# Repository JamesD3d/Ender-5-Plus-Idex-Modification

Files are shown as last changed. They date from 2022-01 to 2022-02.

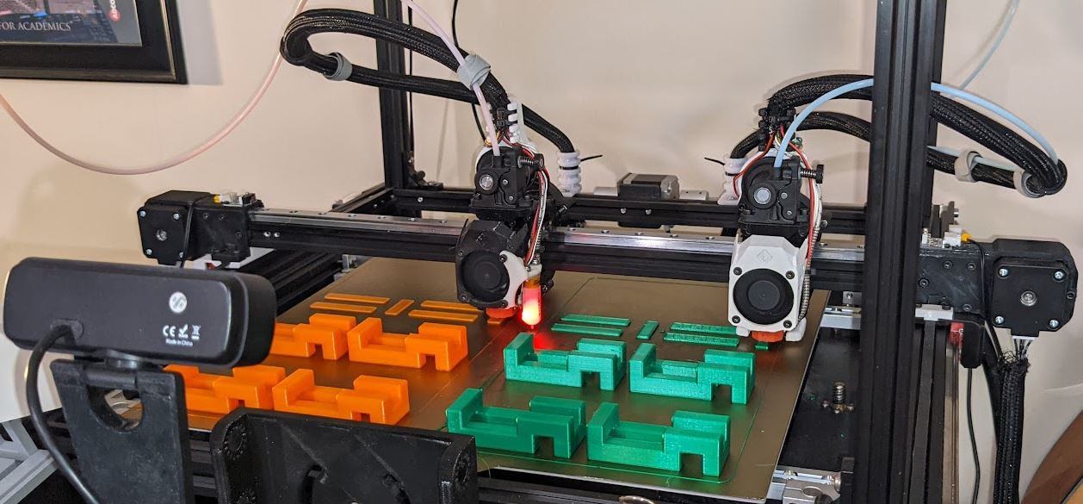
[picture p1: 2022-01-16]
Photos/Capture.JPG

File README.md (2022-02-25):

# Ender-5-Plus-Idex-Modification
This is a repo created for files and software related to the modification of an Enrer 5 plus into an Idex machene. 

Assembly instructions can be found here
<p><a class="inline_disabled" href="https://instructions.online/?id=2779-idex" target="_blank" rel="noopener noreferrer">Assembly Instructions</a></p>  
Firmware modification by S.Downer for Marlin Firmware
Klipper Mirror and Copy modes are not avaliable at this time
RipRap configuration is untested. 

Printer Modifications Require at least 6 independent Drivers
  X0 - X1 E0 - E1 - Y - Z
  X0, E0 = TO X1,E1 =T1
  
 The resulting bed size is as follows
    Stock = 377 x 370
    Dual Color / Full Controll Mode = 350 x 377
    Duplication Mode = 185 x 370
    Mirror Mode = 175 x 370
    
 Printing:
    All files shoud print w/out out supports with sacrafichial layers
    Extra perimiters are recomended. 
    Parts are designed and printed in PETG but ABS should work as well. 
    
 Retained Parts: 
    Many of the stock ender 5+ Parts are reused
    Many Nuts and Bolts
    Stock Y axis Belts
    Stock V slot wheel spacers
    
Eva 2. Tool head
    Please see the eva tool head system for instructions. 
    Most of the parts are customized
        Idex Back Plate
        Fand Duckt
        Universal Face plate
        Copperhead mount
        
The copperhead hotend is highly recomended as it is adjustable and really the only way to get a perfect z offset between both tools. This is a requirement for Duplication and Morror Modes to work.

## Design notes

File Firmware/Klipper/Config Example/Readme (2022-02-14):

The Klipper FIles do not curently support Mirror and Copy modes in Ideax configurations. This is a non functioning example of the config needed once complete.

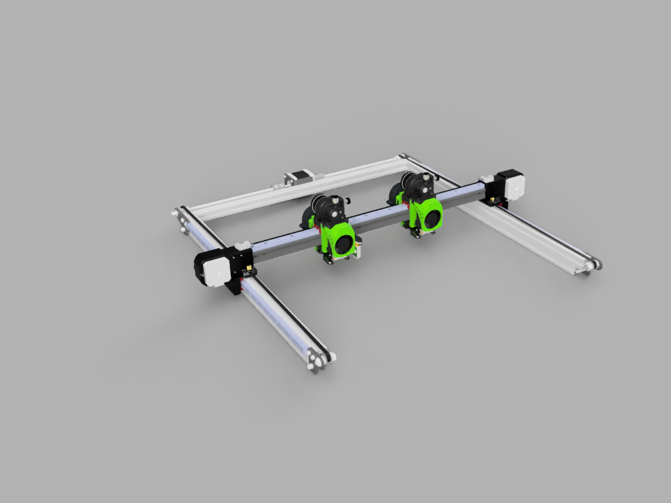
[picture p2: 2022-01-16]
Photos/Ender_5_Plus_Idex_Conversion_2022-Jan-16_10-52-59PM-000_CustomizedView14178243556.png

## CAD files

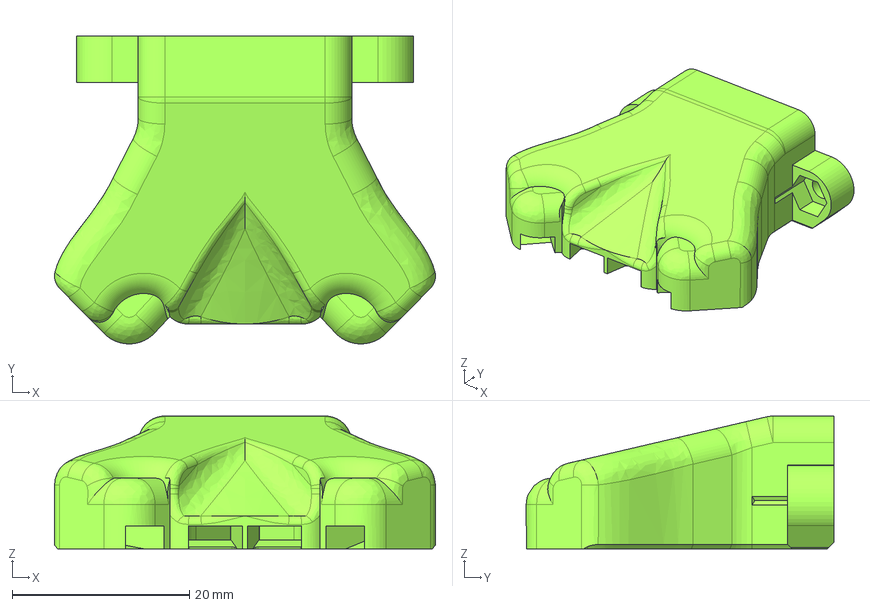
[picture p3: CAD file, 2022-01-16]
.step/S.Downer Fan and Copper/Compact Fan.step
43.0 x 34.7 x 15.0 mm

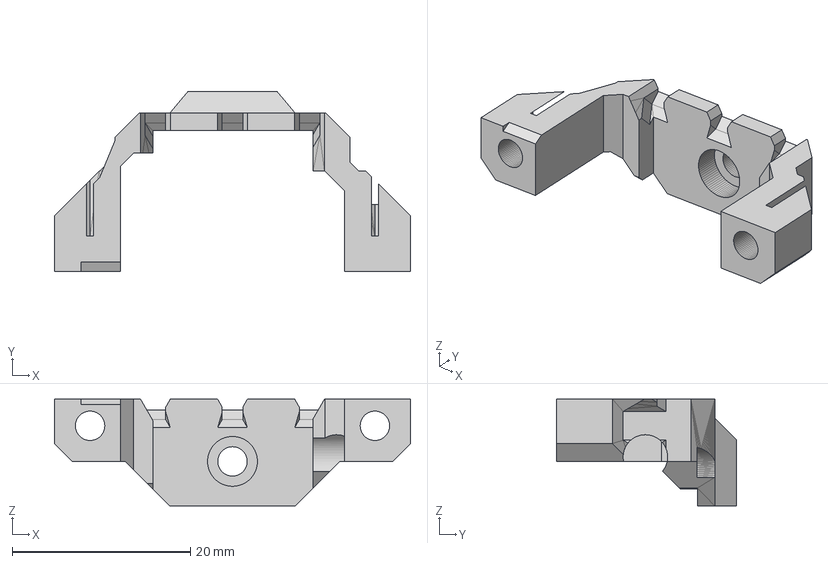
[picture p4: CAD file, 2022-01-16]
.step/S.Downer Fan and Copper/Copperhead Custom Support.step
40.0 x 20.3 x 12.0 mm

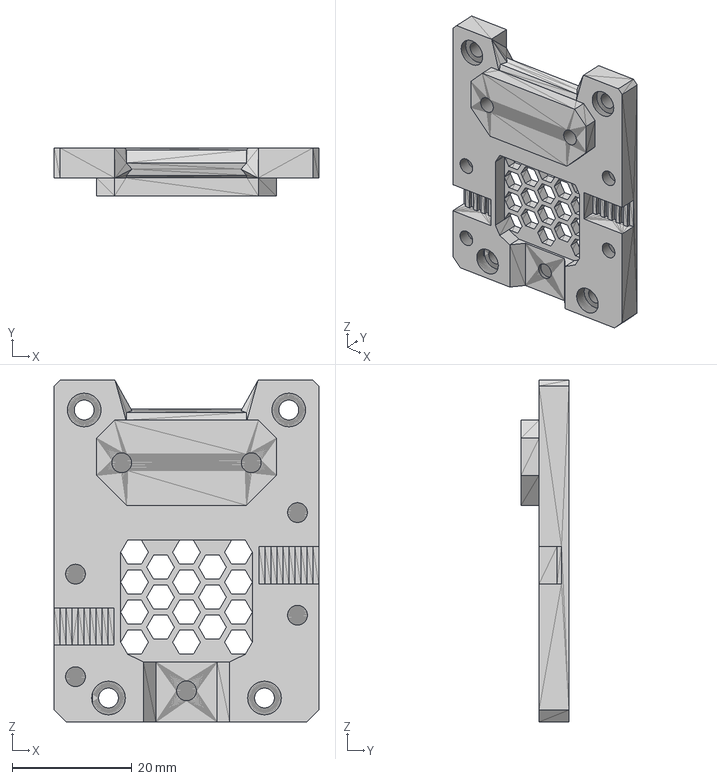
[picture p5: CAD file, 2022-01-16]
.step/S.Downer Fan and Copper/Copperhead X Carriage Front.step
44.1 x 8.00 x 57.0 mm

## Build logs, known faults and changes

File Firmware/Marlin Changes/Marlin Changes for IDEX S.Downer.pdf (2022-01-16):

Purpose of this Document
There is very limited documentation available for a Marlin based IDEX setup, and number of the key settings are quite difficult to work out without lots of trial and error.
The purpose of this document is to describe the main Marlin changes required for an IDEX set up, and to explain what these settings do where necessary.
The document assumes that the reader is familiar with editing Marlin source code, and is able to determine the correct values for the remainder of the configuration required for their particular 3d printer.

Basic hardware requirements for IDEX setup
Stepper Motors
The selected motherboard needs to support a minimum of 6 stepper motors. These are broken down as follows, but the total number will depend on the setup of your particular printer:
- X Axis. 2 identical stepper motors are required, each motor will be responsible for moving 1 of the 2 extruders.
- Y axis. 1 stepper motor
- Z axis. 1 stepper motor (minimum, but 3 independent steppers recommended as best in class solution (note this requires BL touch of equivalent))
- Extruders. 2 identical stepper motors are required, one for each of the two extruders.
For stepper motor selection, regular 42-34 stepper motors with 1.8 degree step angle are recommended. Whatever stepper motor is chosen, it is critical that the correct Vref / current values are configured to ensure correct printer operation.

End stop switches
If you are using a conventional endstop setup (rather than sensorless homing) you will require 1 additional end stop switch on the X Axis.
Note that with an IDEX setup, “Extruder 1” is the left hand extruder and homes to the left hand side of the print bed (the X Min direction), whilst “Extruder 2” is the right hand extruder and homes to the right hand side of the print bed (the X Max direction). This is why 2 end stop switches are required, and later in the Marlin configuration you will see that both XMin and XMax have to be setup correctly.

Choice of Hotend
It is critical with a dual extrusion setup that both nozzles can be adjusted to the same height, which ensures consistent filament extrusion. As a result, it is vital that at least one of the hotends selected has an adjustable height nozzle to match that of the other extruder.
The recommended setup is to use 2 x Copperhead hotends, and a custom mount has been designed to work with the popular EVA2 modular assembly (https://main.eva-3d.page/)

EVA2 is a great choice for an IDEX setup due to its range of supported hardware, and very compact design – ensuring that there is minimal loss of printing real estate on the bed in the X direction due to the IDEX assemblies getting in the way of each other.
Bed Probe
A bed probe such as a BLTouch is optional to this setup. If a bed probe is in use, Marlin expects the probe to be attached to Extruder 1 (the left hand IDEX assembly). This is not configurable without major code changes.

List of Marlin Changes to get IDEX working
configuration.h
Configuration Key | Configuration Value | Notes
#define EXTRUDERS | 2 | Change the default value from 1 to 2. This tells Marlin that you have a dual extrusion setup.

#define HOTEND_OFFSET_X | 0 | Leave this at the default value of zero. The settings later will deal with the relative positions of the two extruders.

#define USE_XMIN_PLUG | Enable by removing the “//” | As mentioned earlier, the two extruders home at opposite ends of the X axis. The XMin endstop is used for extruder 1.

#define TEMP_SENSOR_0 #define TEMP_SENSOR_1 | Enable by removing the “//” for “TEMP_SENSOR_1”. | Each hotend will have its own thermistor, and the second extruder needs enabling to support this. Ender the appropriate value for your thermistors

#define X_DRIVER_TYPE #define X2_DRIVER_TYPE | Enable “#define X2_DRIVER_TYPE” by removing the “//”. | Configure the correct stepper drivers for each X axis motor. Note that there may be other dependent values required for X2 depending on the stepper drivers, e.g. trinamic driver current in advanced configuration.

#define E0_DRIVER_TYPE #define E1_DRIVER_TYPE | Enable “#define E1_DRIVER_TYPE” by removing the “//”. | Configure the correct stepper drivers for each extruder motor. Note that there may be other dependent values required for E1 depending on the stepper drivers, e.g. trinamic driver current in advanced configuration.

INVERT_E0_DIR INVERT_E1_DIR | Set INVERT_E1_DIR to same value as INVERT_E0_DIR | This is a software setting that determines which way the

| | stepper motors move (can be adjusted by changing cable wiring layout too).
#define X_BED_SIZE #define Y_BED_SIZE | Example for Ender 5 Plus: 377 350 | The normal printable area may be different from the physical bed size. IDEX complicates this further as each extruder may not be able to reach part of the bed at each extreme of the X Axis. It is recommended you configure the X_BED_SIZE value to the physical dimensions of the bed. This value is used to determine the relative extruder position, and using the full size also means you lose the lowest possible amount of printing space.

#define X_MIN_POS | Example for Ender 5 Plus: -36 | When the left hand extruder homes, it will be parked off the left hand side of the bed. The default Marlin behaviour is to treat this as X=0. This needs to be adjusted so that X=0 is the left hand edge of the printer bed. The exact value used here will depend on your printer setup, but for an IDEX setup on a Ender 5+, this is a guide.

#define X_MAX_POS | Example for Ender 5 Plus: 412 | Similarly to above, when the right hand extruder is homed, it will move to the X axis maximum end stop. The default Marlin behaviour would be to assume this is equal to the maximum configured X axis bed size (e.g. 377). As at the maximum end stop position, extruder 2 is parked off the right hand edge of the bed, this is a value >377.

412 is the required
approximate value for a IDEX setup on a Ender 5+.

Configuration_adv.h
define X_CURRENT
define X2_CURRENT
define E0_CURRENT
define E1_CURRENT

Values suitable for your
stepper motors.

If you are using Trinamic
stepper drivers, you need to configure the correct current values for your motors.
Choosing too low a value will cause your motors to skip
steps, and too high will
cause overheating and
shorten their life.

A good rule of thumb:

Take the manufacturers
current specification for the motor, e.g. 1.5amps.

Divide this by the RMS (root mean square) value of 1.4. e.g. 1.5amps / 1.4 = 1.071 amps.

Take 80% of this value = 857 (rounded to 850).

#define DUAL_X_CARRIAGE | Enable by removing the “//” | Tells Marling you have an IDEX dual extrusion setup.

#define X1_MIN_POS | X_MIN_POS | Ensures that the IDEX minimum X value is the same as previously configured

//#define X1_MAX_POS X_BED_SIZE | Disable by putting in the “//” | Not required
#define X1_MAX_POS | 342 | This is used in conjunction with X_MIN_POS to determine the maximum position that the left extruder can move to. Adjust X_MIN_POS first to get X=0 position equal to where the L/H extruder nozzle is just on the bed at the left edge, then adjust this value and increase to the maximum possible value

| | before the extruders touch when right hand extruder is parked, and left hand extruder has been moved to maximum value.
#define X2_MIN_POS | 35 | This controls how far left the right hand extruder can move. It should be set to the lowest value possible before the extruders touch when the left hand extruder is parked, and the right hand extruder is moved as far left as possible.

#define X2_MAX_POS | 412 | Should be the same as X_MAX_POS. It is the X value when the right hand extruder is parked.

#define X2_HOME_DIR | 1 | Ensures the right hand extruder homes towards the maximum endstop position.

#define X2_HOME_POS | X2_MAX_POS | Controls the parking position of the right hand extruder

DEFAULT_DUPLICATION_X_OFFSET | 188 | If you enable duplication mode on the printer, this controls the distance from which the two parts are printed from eachother.
#define PID_PARAMS_PER_HOTEND | Enable by removing the “//” | Even with 2 identical hotends / heater cartridges / thermistors, the PID values to get consistent temperatures will be different. Enable this to allow each hotend to have its own PID tuning.

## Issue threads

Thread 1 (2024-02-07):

Questions: ender 5 and eva 3 toolhead compatibility

montyx00, 2024-02-07:
Hello!
Thanks for the awesome project at first. Mostly for the very precise assembly instructions.
As far as I see you use EVA 2.4 toolhead in your project. Is this possible to convert it to EVA3 too?
Also I'm going to mod both normal e5 and e5+ machines. Do you have any experience with the e5?
I've checked the rail dimensions and as far as I see in case of e5 the rails are:
X gantry: 370mm
Y axis: 340mm

Can you verify it, or I'll be the very first dummy to experience with it?

Thanks a lot in advance, and have a great day!

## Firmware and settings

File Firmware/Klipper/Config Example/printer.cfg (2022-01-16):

# This file contains common pin mappings for the BTT OctoPus board.
# To use this config, the firmware should be compiled for the STM32F446.
# When calling "menuconfig", enable "extra low-level configuration setup"
# and select the "12MHz crystal" as clock reference
# For flashing, write the compiled klipper.bin to memory location 0x08008000 whit 32KB bootloader offset

# See the example.cfg file for a description of available parameters

# FIRMWARE_VERSION:v0.9.1-562-gacdad764 
# FIRMWARE_NAME:Klipper


#############################################
# pin mappings for BTT OCTOPUS V1.0 
#############################################

[mcu]
serial: /dev/serial/by-id/usb-Klipper_stm32f446xx_38001F00105053424E363620-if00

baud: 250000
restart_method:command

[printer]
kinematics: cartesian
max_velocity: 200
max_accel: 1500
max_accel_to_decel: 750
max_z_velocity: 15
max_z_accel: 30
square_corner_velocity: 5

[input_shaper]


########################################
# BL-Touch configuration
########################################

[bltouch]
sensor_pin: ^PB7
control_pin: PB6
x_offset: 0
y_offset: 0
z_offset: 4.58
speed: 2.0
samples: 2
sample_retract_dist: 3.31
probe_with_touch_mode: True

#############################################
# MOTOR MAP
#############################################
# MOTOR 0 X1
[stepper_x]
step_pin: PG0
dir_pin: !PG1
enable_pin: !PF15
microsteps: 16
rotation_distance: 40
endstop_pin: PG6  # for X-max
position_endstop: -36
position_min: -36
position_max: 357
homing_speed: 100

# MOTOR 2 Y
[stepper_y]
step_pin: PF11
dir_pin: !PG3
enable_pin: !PG5
microsteps: 16
rotation_distance: 40
endstop_pin: ^PG10
position_endstop: 370
position_min: 0
position_max: 370
homing_speed: 85

# MOTOR 3 Z0
[stepper_z]
step_pin: !PG4
dir_pin: !PC1
enable_pin: !PA0
microsteps: 16
rotation_distance: 4
#endstop_pin: PG11
#position_endstop: 0
position_max: 410
endstop_pin: probe:z_virtual_endstop
position_min: -5 # The Z carriage may need to travel below the Z=0

# MOTOR 4 Z1
[stepper_z1]
step_pin: !PF9
dir_pin: !PF10
enable_pin: !PG2
microsteps: 16
rotation_distance: 4

# MOTOR 5 E0
[extruder]
step_pin: PC13
dir_pin: PF0
enable_pin: !PF1
microsteps: 16
#gear_ratio: 7.5:1
rotation_distance: 4.5714
full_steps_per_rotation: 200
nozzle_diameter: 0.600
filament_diameter: 1.750
max_extrude_only_velocity: 60
heater_pin: PA2
sensor_type: EPCOS 100K B57560G104F
sensor_pin: PF4
control: pid
#max_extrude_cross_section: 0.64
max_power: 1
pid_Kp: 22.2
pid_Ki: 1.08
pid_Kd: 114
min_temp: 0
max_temp: 350
min_extrude_temp: 20
max_extrude_only_distance: 200
pressure_advance: 0.057

[heater_bed]
heater_pin: PB10
sensor_type: EPCOS 100K B57560G104F
sensor_pin: PF3
max_power: 0.9
control: pid
pid_Kp: 221.22
pid_Ki: 43.56
pid_Kd: 280.90
min_temp: 0
max_temp: 150

##########################################################
# Definition for the secondary carriage X2 and extruder 1
##########################################################

# MOTOR 1 X2
[dual_carriage]
axis: x
step_pin: PF13
dir_pin: !PF12
enable_pin: !PF14
microsteps: 16
rotation_distance: 40
endstop_pin: ^PG9
position_endstop: 410.1
position_max: 410.1
position_min: 20
homing_speed: 100


# MOTOR 6 E1
[extruder1]
step_pin: PE2
dir_pin: PE3
enable_pin: !PD4
microsteps: 16
#gear_ratio: 7.5:1
rotation_distance: 4.5714
nozzle_diameter: 0.600
full_steps_per_rotation: 200
filament_diameter: 1.750
max_extrude_only_velocity: 60
nozzle_diameter: 0.800
filament_diameter: 1.750
sensor_type: EPCOS 100K B57560G104F
heater_pin: PA3
sensor_pin: PF5
control: pid
#max_extrude_cross_section: 0.64
max_power: 1
pid_Kp: 22.2
pid_Ki: 1.08
pid_Kd: 114
min_temp: 0
max_temp: 350
min_extrude_temp: 20
max_extrude_only_distance: 200
pressure_advance: 0.057

########################################
# Bed mesh configuration
########################################

[bed_mesh]
speed: 100
horizontal_move_z: 8
mesh_min: 75, 50
mesh_max: 300,300
probe_count: 3,3

########################################
# MCU
########################################
[heater_fan T0]
pin: PD13
heater: extruder
heater_temp: 50
fan_speed: 1.0

[heater_fan T1]
pin: PA8
heater: extruder1
heater_temp: 50
fan_speed: 1.0

#[controller_fan controller_fan]
#pin:  PD14

########################################
###    Users Macros                  ###
########################################

[include TMC_2209.cfg]
#[include lcd.cfg]
[include fluidd.cfg]

########################################
###    IDEX mode AUTO_PARK           ###
########################################

[include IDEX_mode.cfg]
[include HOMING.cfg]

########################################
# UNUSED
########################################

# MOTOR 7 NOT IN USE
#[stepper_7]
#step_pin: PE6
#dir_pin: !PA14
#enable_pin: !PE0

#HEATER 3_4
#heater_pin: PB10
#heater_pin: PB11

#SENSOR T2_T3 
#sensor_pin: PF6
#sensor_pin: PF7

#ENDSTOPS
#endstop_pin: PG12 / MOTOR 4
#endstop_pin: PG13 / MOTOR 5
#endstop_pin: PG14 / MOTOR 6
#endstop_pin: PG15 / MOTOR 7

#CONTROLLABLE FAN PINS
#[fan4] pin: PE5
#[fan5] pin: PE5

#*# <---------------------- SAVE_CONFIG ---------------------->
#*# DO NOT EDIT THIS BLOCK OR BELOW. The contents are auto-generated.
#*#
#*# [extruder1]
#*#
#*# [extruder]
#*#
#*# [heater_bed]
#*#
#*# [bed_mesh default]
#*# version = 1
#*# points =
#*# 	  0.099478, 0.110103, -0.003022
#*# 	  0.089478, 0.026978, 0.013853
#*# 	  0.018228, -0.024272, -0.013647
#*# tension = 0.2
#*# min_x = 75.0
#*# algo = lagrange
#*# y_count = 3
#*# mesh_y_pps = 2
#*# min_y = 50.0
#*# x_count = 3
#*# max_y = 300.0
#*# mesh_x_pps = 2
#*# max_x = 300.0

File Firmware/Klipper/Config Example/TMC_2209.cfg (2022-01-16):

########################################
# TMC 2209 stepper driver configuration
########################################

#[idle_timeout]
#gcode:120

[tmc2209 stepper_x]
uart_pin: PC4
run_current: .8
hold_current: 0.5
stealthchop_threshold: 99999
#diag_pin:

[tmc2209 stepper_y]
uart_pin: PC6
run_current: .8
hold_current: 0.5
stealthchop_threshold: 99999
#diag_pin:

[tmc2209 stepper_z]
uart_pin: PC7
run_current: .8
hold_current: 0.5
stealthchop_threshold: 99999
#diag_pin:

[tmc2209 stepper_z1]
uart_pin: PF2
run_current: .8
hold_current: 0.5
stealthchop_threshold: 99999
#diag_pin:

[tmc2209 extruder]
uart_pin: PE4
run_current: 0.35
hold_current: 0.01
#diag_pin:

[tmc2209 dual_carriage]
uart_pin: PD11
run_current: .8
hold_current: 0.5
stealthchop_threshold: 99999
#diag_pin:

[tmc2209 extruder1]
uart_pin: PE1
run_current: 0.35
hold_current: 0.01
#diag_pin:

#[tmc2209 MOTOR_7]
#uart_pin: Pd3
#run_current: 0.35
#hold_current: 0
#stealthchop_threshold: 30
#diag_pin:

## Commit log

2022-01-16 Ender 5+ / Eva2.3 modifucations
    I know just enought about CAD to be dangerious. this is my best atempt.
2022-01-16 Ender 5+ Gantry and Eva2.3 STEP Files
2022-01-16 Marlin Mods for IDEX cont. S.Downer
    List of Marlin Modifaications to config.h and config.adv.h files needed
    Mirror, Duplication, and Multi materal modes functional.
    Thanks to S.Downer for his help with this
2022-01-16 Rename .STEP Files to .STEP Files Gantry & Eva Mods
2022-01-16 Create Marlin
2022-01-16 Create Klipper
2022-01-16 Rename .STEP Files Gantry & Eva Mods to .STEP Files
2022-01-16 Create Gantry & Eva Mods
2022-01-16 Create S.Downer Fan and Copperhead
2022-01-16 Rename Gantry & Eva Mods to Full Mod Gantry and Eva Mods
2022-01-16 Create Full Plate
2022-01-16 Create Marlin Changes
2022-01-16 Rename .step/S.Downer Fan and Copperhead to .step/S.Downer Fan and Copper/head
2022-02-14 Create Assembly
2022-02-14 Update Assembly
